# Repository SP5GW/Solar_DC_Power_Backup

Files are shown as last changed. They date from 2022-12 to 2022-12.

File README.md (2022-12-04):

**<p style="text-align: center;">Solar - DC Power Backup Module</p>**

<p align="center">
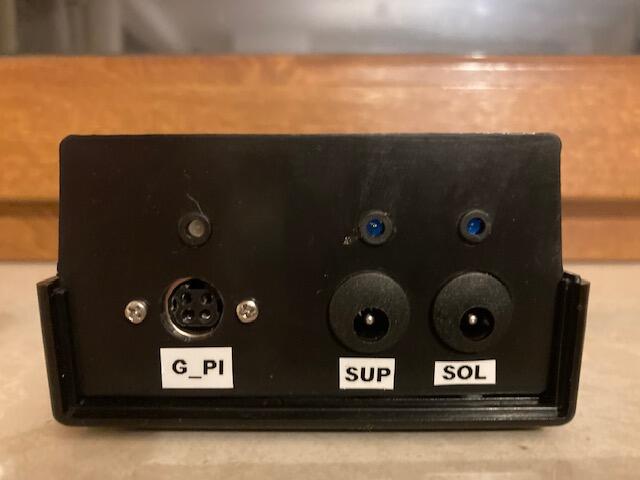
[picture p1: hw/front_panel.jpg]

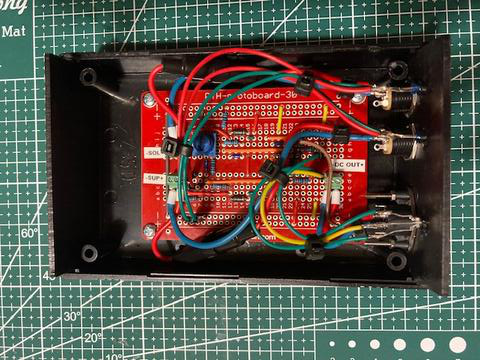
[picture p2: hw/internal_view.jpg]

</p>

Solar - DC Power Backup Module is an accessory for gardenpi controller allowing the device to be powered from dc power supply in situations when battery storing solar energy is insufficiently charged. Design has been based on LM358 operation amplifier configured as analog signal comparator.

**Key Features:**

- It is possible to connect 12V DC external power supply using socket marked as SUP
- It is possible to connect  12V DC input from solar panel voltage regulator using socket marked as SOL
- Whenever input voltage is present on SOL or SUP inputs, blue LED is switched-on above respective socket
- If solar panel voltage regulator detects that battery output voltage is 11.1V or less then output voltage from the regulator is set to 0V on SOL input until battery is charged again to 12.5V.
- If voltage at SOL input is 0V then voltage from SUP input is directed to output marked as G_PI
- When G_PI voltage is routed from SOL input then LED above G_PI socket turns green.
- When G_PI voltage is routed from SUP input then LED above G_PI socket turns red.
- Device connected to G_PI (garden pi controller) is provided with power as long as nominal voltage on either SOL or SUP inputs is present. 
- Voltage from SOL input is always routed to G_PI output with higher priority then from SUP input.

**Design and Build Instructions**

HW design has been described in the following files:

* [Bill of Materials](./docs/hw_bom.txt)
* [Circuit diagram](./docs/solar_dc_power_backup_schematics.pdf)
* [HW Photos](./hw/)

This is hardware only project. No software is developed as part of Solar - DC Power Backup Module. Digital signal indicating source of DC voltage is however available on one of the G_PI socket pins.

**Initial Configuration**

* Not Applicable

**Device Operation**

Device does not require special maintenance, if GardenPi operates from location where there is no wifi access its RTC can drift so it is desirable to bring it within wifi coverage from time to time. Such behavior can be expected, but was not observed in real life yet.

**Release History**

* Release 1.0 - November 2022 - final version of the device released, no more updated are planned.
	
**Planned Functionality**

* Not Applicable

Comments or Questions can be directed to: andrzej@mazur.info

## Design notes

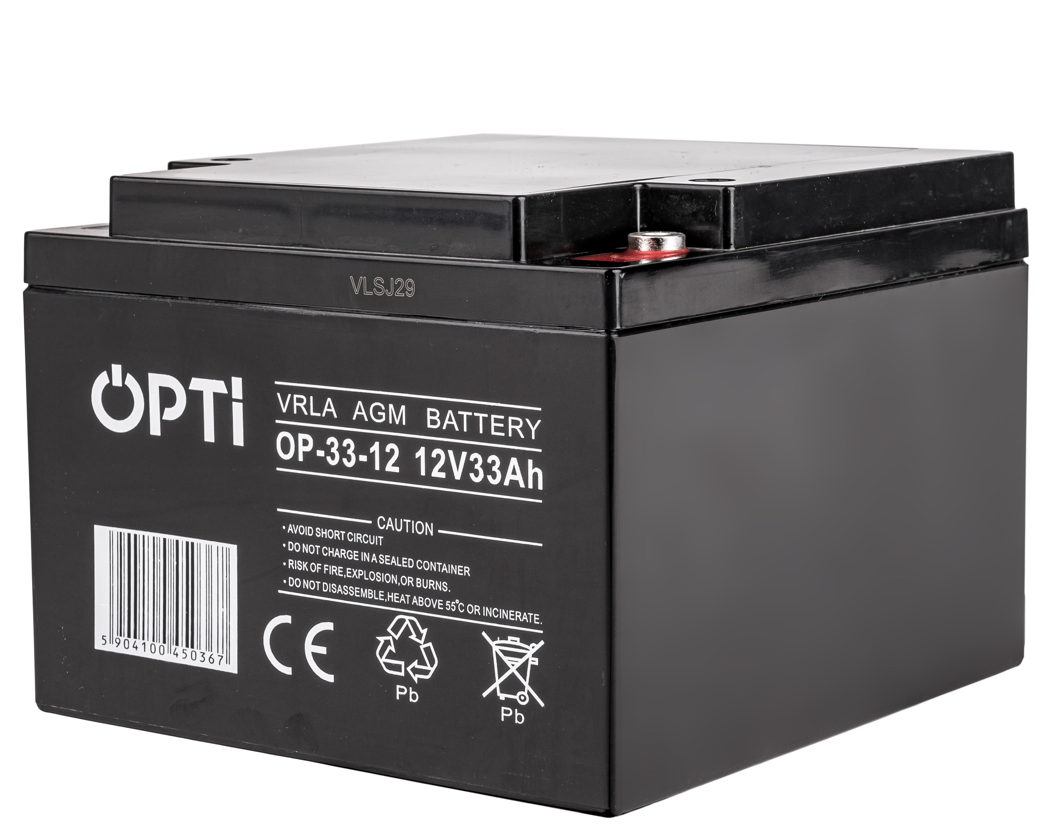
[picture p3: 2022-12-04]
hw/battery/JQGGkHEJEAVccRUCTbfQ.jpg

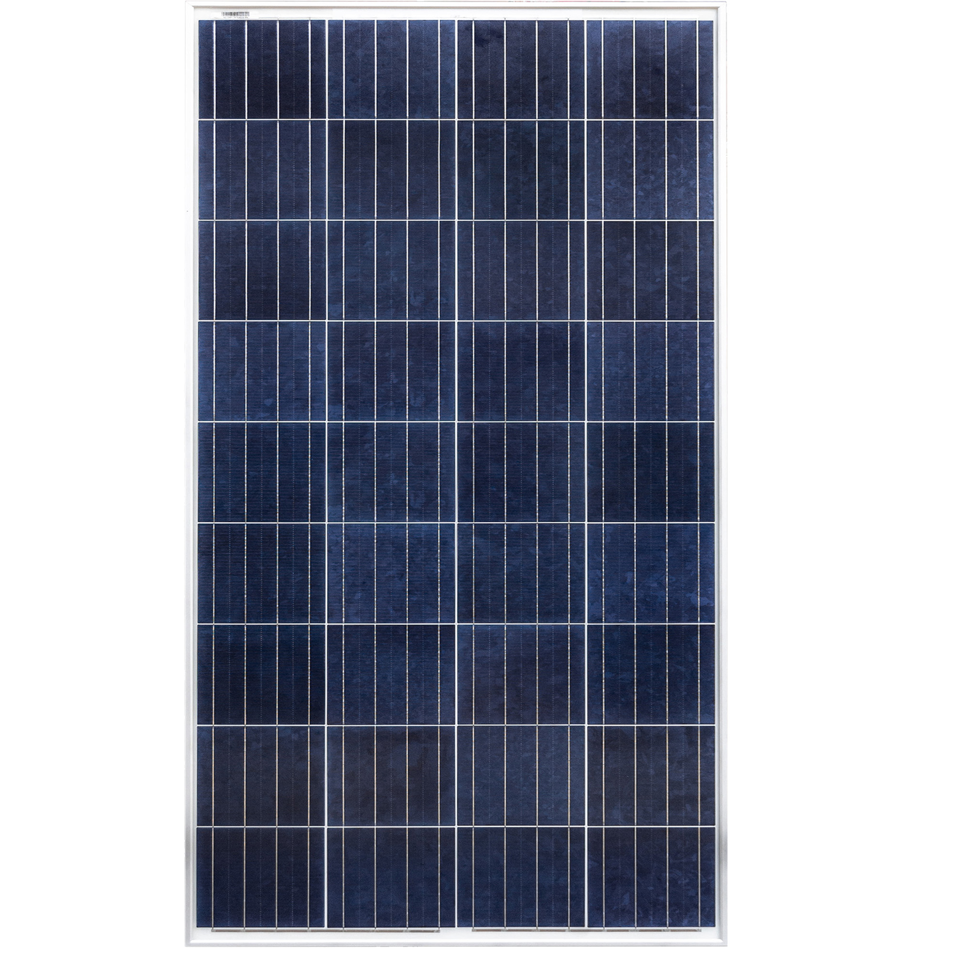
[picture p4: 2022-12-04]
hw/solar_panel_and_regulator/kXfNHhHafMQFYWPCQAKk.jpg

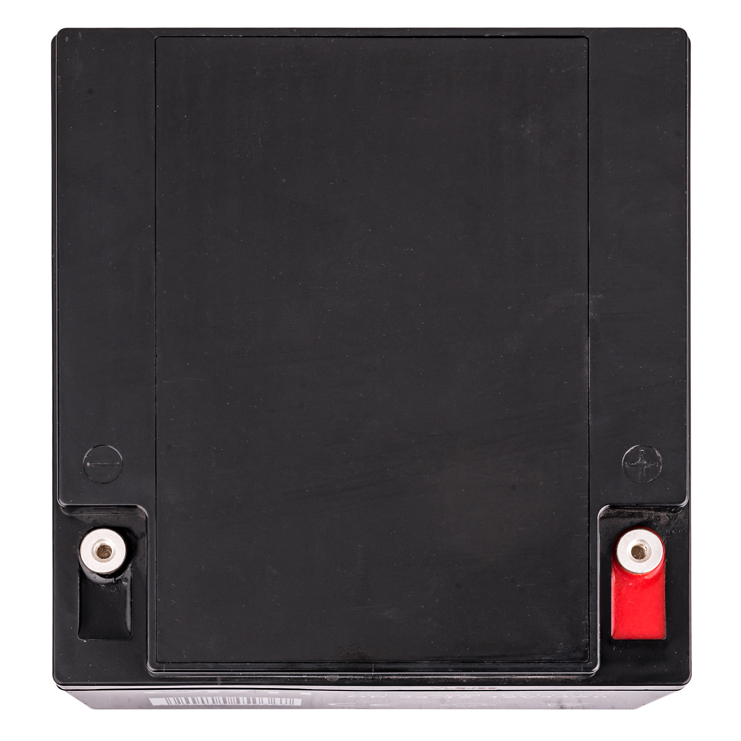
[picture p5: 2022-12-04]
hw/battery/ZFFkeJhHBSMAcXfKhWHH.jpg

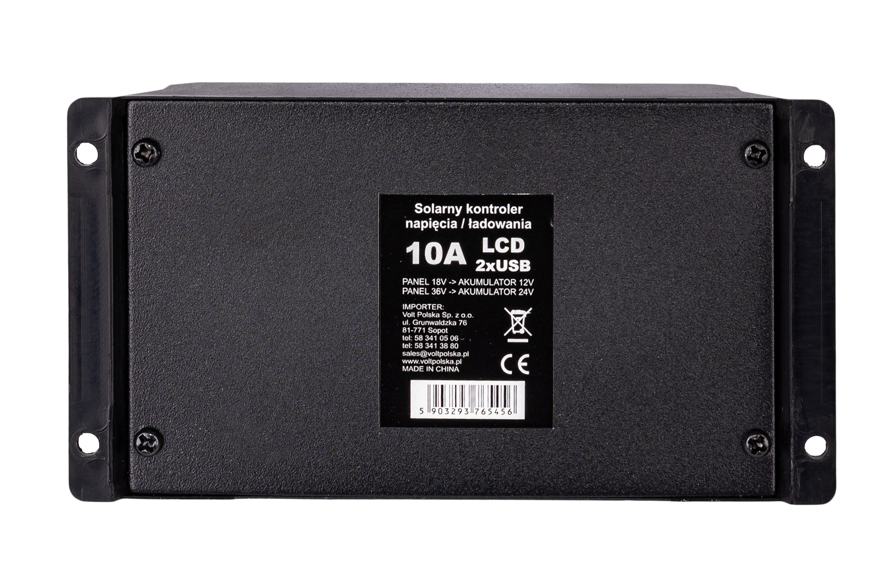
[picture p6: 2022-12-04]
hw/solar_panel_and_regulator/eZPkPVESGcTcFcFjbQZR.jpg

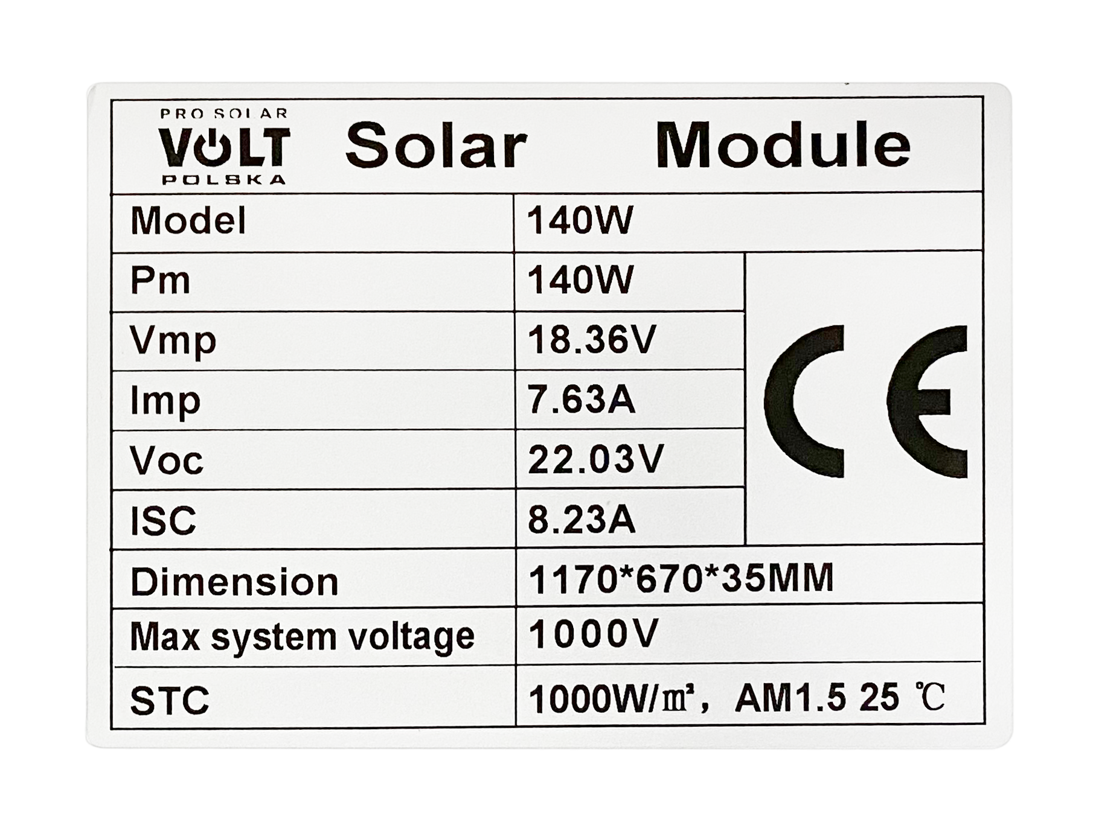
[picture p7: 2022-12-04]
hw/solar_panel_and_regulator/XPRhJjgTRNFVFBUcTSNB.png

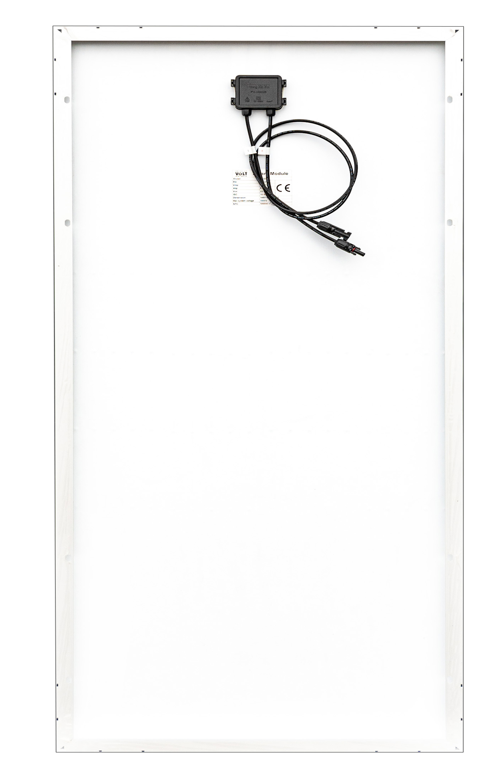
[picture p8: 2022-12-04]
hw/solar_panel_and_regulator/hZTAhUTHPFfjKCRNMNSe.jpg

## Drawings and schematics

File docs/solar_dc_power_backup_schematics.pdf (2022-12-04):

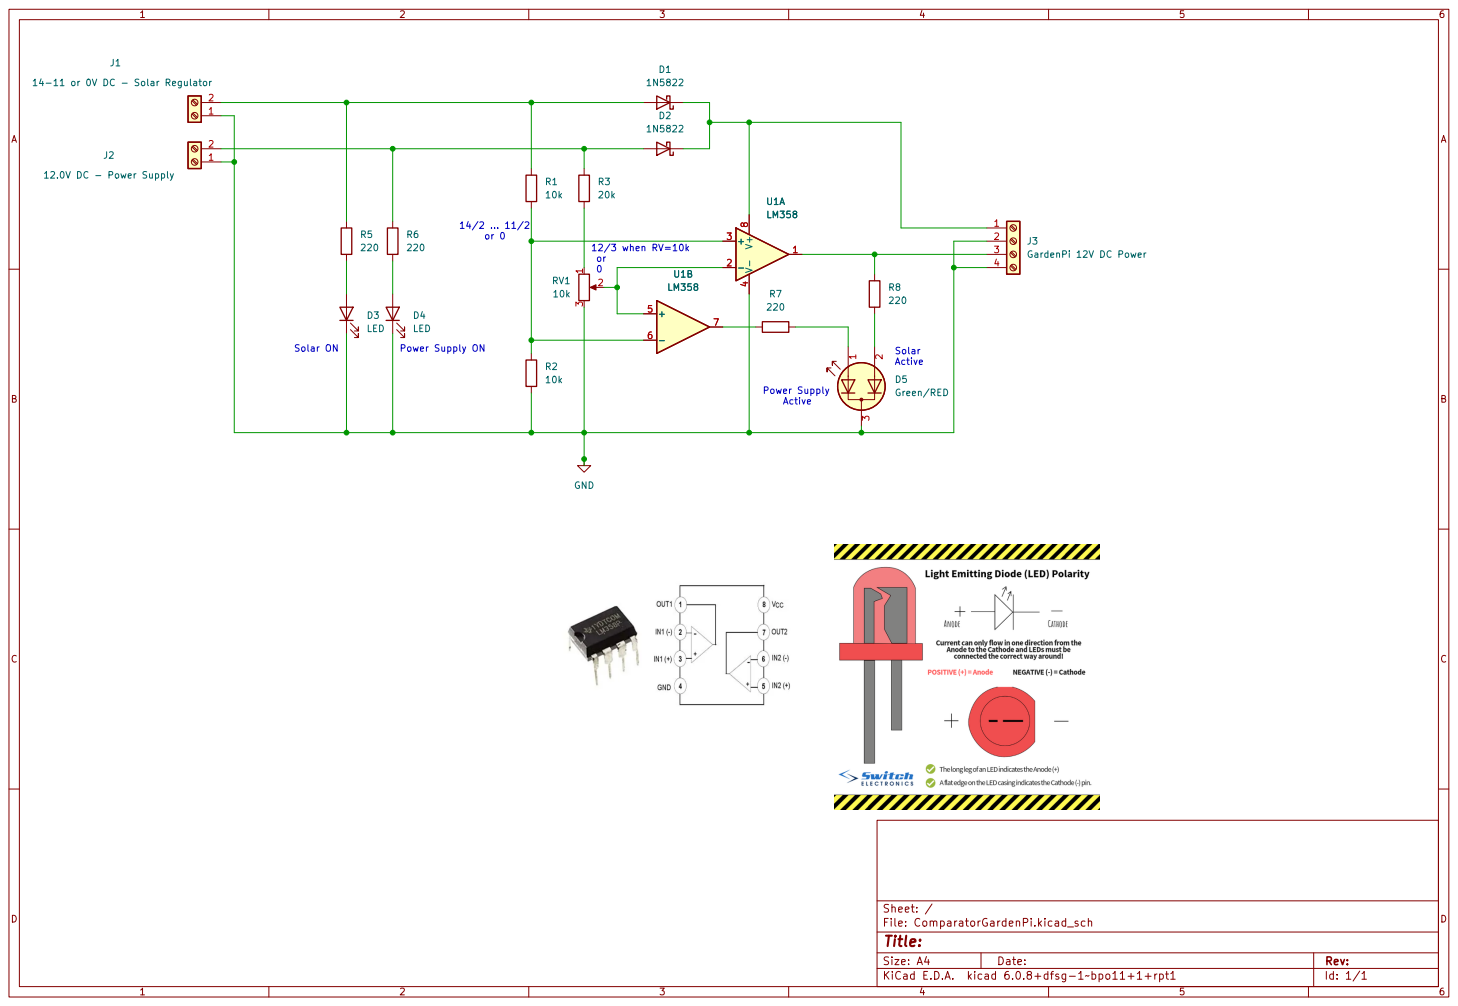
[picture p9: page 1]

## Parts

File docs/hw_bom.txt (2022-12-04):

Bill of Materials for Solar-DC Power Backup Rev 1.0

=============================================================================================================================
Device Type					Model						Qty	Seller:product code
=============================================================================================================================
Resistor					220ohm						 4	AVT
Resistor					10k						 2	AVT
Resistor					20k						 1	AVT
Mounting Potentiometer				10k						 1	AVT
Schottky Diode					1N5822						 2	AVT
LED 3mm						bi-color (red,green)				 1	AVT
Dual Comparator					LM358						 1	AVT
Screw Connector					2 fields, raster: 3.5mm, height=8.6mm 		 3	AVT
Through Hole 3mm Short Lens Blue                Lumex SSL-LX3044USBC                             2      Mouser: 696-SSL-LX3044USBC
Plastic Bevel LED Holder 3mm                    Adafruit accessories                             3      Mouser: 485-2179
Black Chassie axbxcmm	                        Kradex 	                                         1      AVT:
Kycon DC Power Connector                        KPPX-4P                                          1      Mouser: 806-KPPX-4P
Kycon DC Power Connector                        KPJX-PM-4S-S                                     1      Mouser: 806-KPJX-PM-4S-S
screws M2x20                                    length: 20mm, diameter: M2 (2mm)                 2      Allegro/jack20prv
nuts M2                                         diameter:M2 (2mm)                                2      Allegro/jack20prv
fuse						10A						 2	AVT
fuse socket					5 x 20 mm with wires				 2 	Botland
DC Barrel Jack - 5.5x2.1mm, Panel Mount		2179						 2	Botland: KAB-09351
Accessories Solderable Breadboard		SparkFun PRT-12070				 1	Mouser: 474-PRT-12070
Solar kit (140W panel with 12V/10A regulator)	VoLT PL Solarny140 ZES262			 1	Tooles.pl					
VRLA AGM Battery				OP-33-12 12V33Ah				 1	Tooles.pl
